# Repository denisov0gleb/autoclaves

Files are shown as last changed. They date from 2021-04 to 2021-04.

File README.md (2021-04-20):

# Autoclaves #

[OpenSCAD](http://www.openscad.org) file to generate autoclaves for 3D printing by polypropylene.

Keep generated *STL* files in **STLs** folder.

## Capabilities ##

You can specify autoclave volume (in microliters) and/or inside cavity diameter (in millimeters).

**All** wall thickness are required.

### Single autoclave ###

*Examples:*

1. Both volume and diameter are given:
```openscad
autoclave(volume=1000, d=12.408, bottom=5, top=5, wall=5);
```

2. Only volume is given, diameter is calculated:
```openscad
autoclave(volume=1000, bottom=5, top=5, wall=5);
```

3. Only diameter is given, volume is calculated:
```openscad
autoclave(d=12.408, bottom=5, top=5, wall=5);
```

### 3x3 autoclave ###

Additional distance separator **delta**. By default **delta = 1**.

1. Only **volume** is given, **diameter** is calculated, **delta** is changed:
```openscad
autoclave_3x3(volume=1000, bottom=5, top=5, wall=5, delta=2);
```

2. Only **volume** is given, **diameter** is calculated, **delta** is default:
```openscad
autoclave_3x3(volume=1000, bottom=5, top=5, wall=5);
```

### Squared nxn autoclave ###

**n** - number of autoclaves in each row. By default **n = 2**.

Additional distance separator **delta**. By default **delta = 1**.

1. Only **volume** is given, **diameter** is calculated, **n** and **delta** are default:
```openscad
autoclave_nxn(volume=1000, bottom=5, top=5, wall=5);
```

2. Only **volume** is given, **diameter** is calculated, **delta** is default:
```openscad
autoclave_nxn(volume=1000, bottom=5, top=5, wall=5, n=5);
```

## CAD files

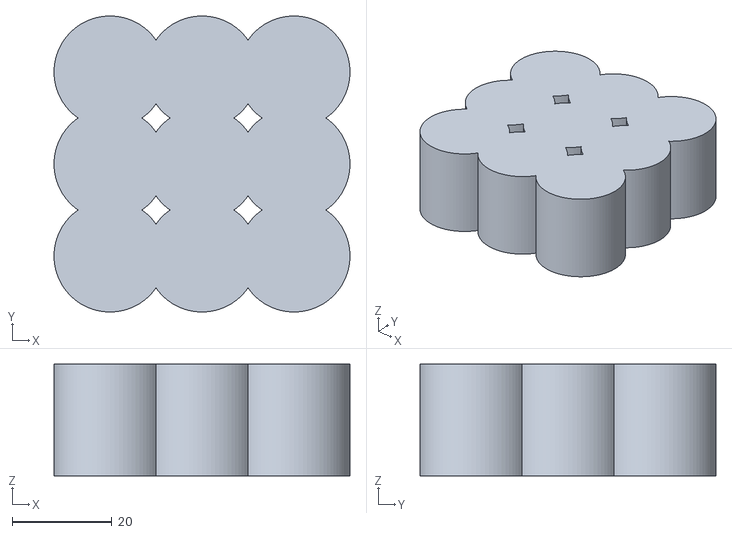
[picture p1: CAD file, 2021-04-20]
STLs/autoclave_3x3_1mL.stl
59.2 x 59.2 x 22.4

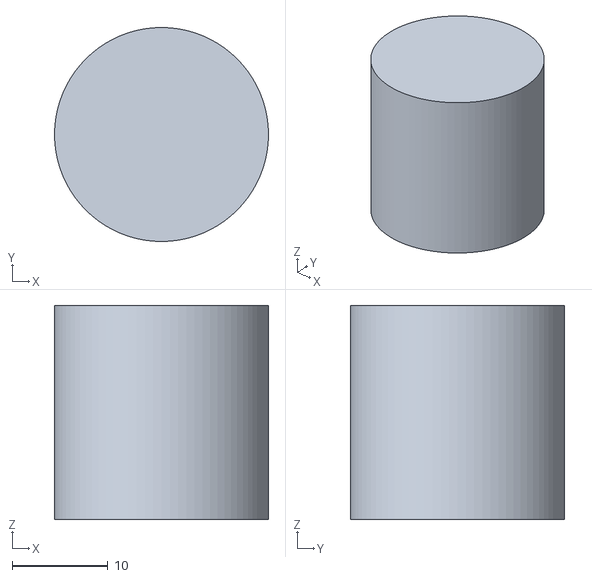
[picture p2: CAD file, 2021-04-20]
STLs/single_autoclave_1mL.stl
22.4 x 22.4 x 22.4

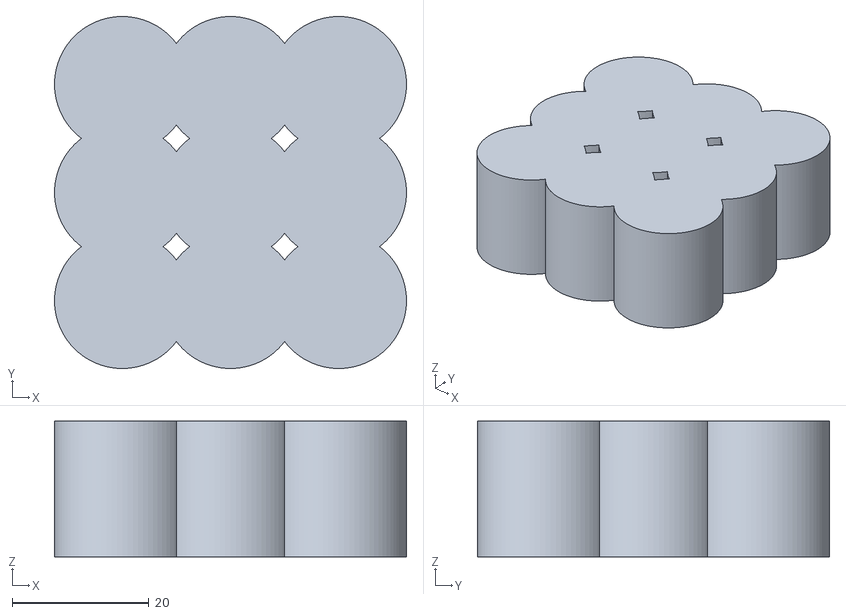
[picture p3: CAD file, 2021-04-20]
STLs/autoclave_3x3_0.5mL.stl
51.5 x 51.5 x 19.8

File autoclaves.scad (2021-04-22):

// Set true of false
SHOW_CAVITY = true;

fn_all = 80;

/*
 ******************************************************************************************
 *                                     Main                                               *
 ******************************************************************************************
 */

// Single autoclave:
autoclave(volume=1000, bottom=5, top=5, wall=5);

// 3x3 autoclave:
// autoclave_3x3(volume=1000, bottom=5, top=5, wall=5);

// nxn autoclave:
// autoclave_nxn(volume=1000, bottom=5, top=5, wall=5, n=5);

/*
 ******************************************************************************************
 *                               Functions                                                *
 ******************************************************************************************
 */
function dFromVolume(volume) = pow(volume * 6 / PI, 1/3);
function volumeFromD(d) = PI * pow(d,3) / 6;

/*
 ******************************************************************************************
 *                               Modules                                                  *
 ******************************************************************************************
 */
module sphereCavity(dia)
{
	sphere(d = dia, $fn=fn_all);
}


module centerCavityInAutoclave(height, dia, top)
{
	translate([0, 0, height/2 - dia/2 - top]) children(0);
}


/*
 ******************************************************************************************
 *                               Autoclaves                                               *
 ******************************************************************************************
 */

/*
 * Usage:
 *
 * autoclave(volume=1000, d=12.408, bottom=5, top=5, wall=5);
 *   or
 * autoclave(volume=1000, bottom=5, top=5, wall=5);
 *   or
 * autoclave(d=12.408, bottom=5, top=5, wall=5);
 */
module autoclave(volume, d, bottom, top, wall)
{
	dia = d ? d : dFromVolume(volume);
	vol = volume ? volume : volumeFromD(dia);

	echo("     Autoclave parameters are:");
	echo(Volume=vol, d=dia, bottom=bottom, top=top, wall=wall);

	h_cyl = dia + bottom + top;
	d_cyl = dia + 2*wall;

	if(!SHOW_CAVITY)
	{
		difference()
		{
			cylinder(d = d_cyl, h = h_cyl, $fn = fn_all, center=true);
			centerCavityInAutoclave(h_cyl, dia, top) sphereCavity(dia);
		}
	}
	else
	{
		centerCavityInAutoclave(h_cyl, dia, top) sphereCavity(dia);
		#cylinder(d = d_cyl, h = h_cyl, $fn = fn_all, center=true);
	}
}


/*
 * Usage:
 * autoclave_3x3(volume=1000, bottom=5, top=5, wall=5, delta=2);
 * autoclave_3x3(volume=1000, bottom=5, top=5, wall=5, delta=2);
 *   or
 * autoclave_3x3(volume=1000, bottom=5, top=5, wall=5);
 */
module autoclave_3x3(volume, d, bottom, top, wall, delta=1)
{
	dia = d ? d : dFromVolume(volume);
	vol = volume ? volume : volumeFromD(dia);

	h_cyl = dia + bottom + top;
	d_cyl = dia + 2*wall;

	D = d_cyl/2 + dia/2; // Distance between centers
	delta = delta ? delta: 1; // additional separation
	for(i = [0 : 2])
		for(j = [0 : 2])
			translate([i*(D + delta), j*(D + delta), 0])
				autoclave(volume=vol, d=dia, bottom=bottom, top=top, wall=wall);
}


/*
 * Usage:
 * autoclave_nxn(volume=1000, bottom=5, top=5, wall=5);
 *   or
 * autoclave_nxn(volume=1000, bottom=5, top=5, wall=5, n=5);
 */
module autoclave_nxn(n, volume, d, bottom, top, wall, delta=1)
{
	number = n ? n : 2;
	dia = d ? d : dFromVolume(volume);
	vol = volume ? volume : volumeFromD(dia);

	h_cyl = dia + bottom + top;
	d_cyl = dia + 2*wall;

	D = d_cyl/2 + dia/2; // Distance between centers
	delta = delta ? delta: 1; // additional separation
	for(i = [0 : number - 1])
		for(j = [0 : number - 1])
			translate([i*(D + delta), j*(D + delta), 0])
				autoclave(volume=vol, d=dia, bottom=bottom, top=top, wall=wall);
}

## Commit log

2019-02-21 Add rounded and cutted conus autoclaves [dgl]
    [conus-autoclave.scad, conus-autoclave.stl, rounded-autoclave.scad]
2019-02-21 Add round autoclave with cone china-like hat; spelling correction [dgl]
    [rounded-autoclave.scad, rounded-with-hat-autoclave.scad]
2019-02-21 Change overlap from 20% to 75%; cyclic bottom layer; add gcode folder [dgl]
    [rounded-autoclave.scad]
2019-02-21 Add Slicer Properties folder with current PP 0.5 [dgl]
    Have some minor problem during printing. The nozzle left a scratch on
    bottom layers. Added Z-lift of 0.2 mm, maybe it will help.
2019-02-22 Add Petr's multiple autoclaves code [dgl]
    [multiple-autoclaves.scad]
2019-02-22 Add rounded-only multiple autoclaves [dgl]
    [multiple-autoclaves.scad, rounded-autoclave.scad]
2019-02-22 Update code to use rounded autoclave in multiple code [dgl]
    [multiple-autoclaves.scad, rounded-autoclave.scad]
2019-02-22 Refactor all code; add multiple file usage [dgl]
    [cone-autoclave.scad, multiple-autoclaves.scad, rounded-autoclave.scad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]
2019-02-22 Change layer height from 0.25 to 0.15 mm; 3mm wall [dgl]
    [rounded-autoclave.scad, variables.scad]
2019-02-25 Print with lower speed and higher temperature [dgl]
    [conus-autoclave.scad]
2019-02-27 0.15 mm height, 3mm wall, T=240C, 0.5mL H2O, v=700mm/min [dgl]
2019-03-01 Success in 1 hour heating: 1.1 multiplier, T=240, 3mm all wall [dgl]
    [variables.scad]
2019-03-01 Switch to 4 mm wall and T=250 [dgl]
    [cone-autoclave.scad, conus-autoclave.scad, conus-autoclave.stl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]
2019-03-04 Success! 1 and 3 hours heating [dgl]
    Parameters: T=245, multiplier=1.1, wall=4mm, v=700
    Leak: 1 hour -> 0.0029 g
    3 hours -> 0.0084 g
2019-03-05 Print faster, v=800 [dgl]
2019-03-25 Single autoclave, bottom=6mm, v=950, m=1.2, h=0.15 [dgl]
    [rounded-autoclave.scad, single_rounded_autoclave.stl, variables.scad]
2021-04-20 Rewrite all code from the beginning [dgl]
    [autoclave_3x3_0.5mL.stl, autoclave_3x3_1mL.stl, autoclaves.scad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]
2021-04-20 Add README [dgl]
    [autoclaves.scad]
2021-04-22 Move editable code to the file beginnig [dgl]
    [autoclaves.scad]
